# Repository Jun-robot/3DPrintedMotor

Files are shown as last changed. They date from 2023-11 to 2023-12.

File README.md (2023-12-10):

# 3DPrintedMotor

## Overview
3Dプリンタで作る自作モーターのリポジトリです。

アイデアがより的確に実現できるようになるといいなと思って開発中です。

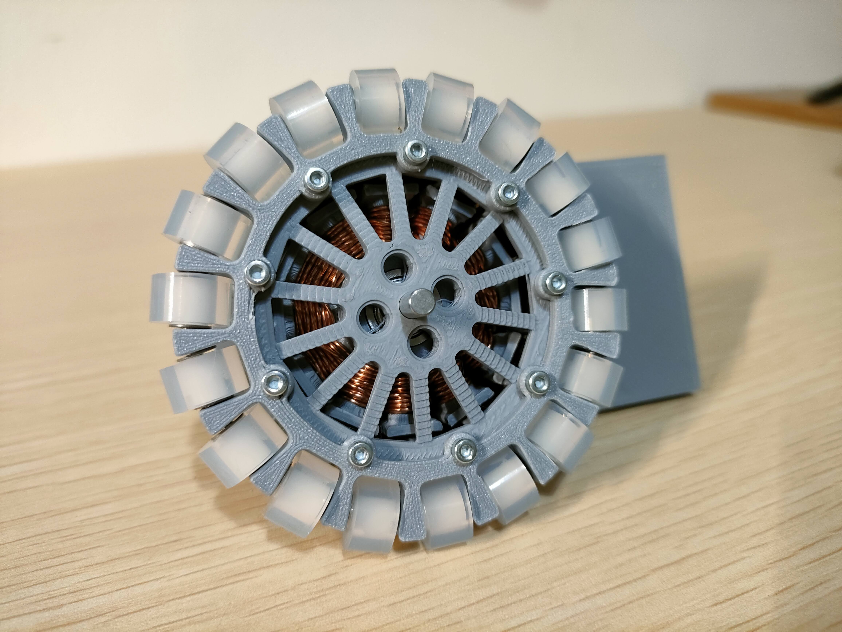
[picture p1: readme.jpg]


## How to make
#### 必要なもの
- 3Dプリンタ
- ネジとかコイルとかベアリングとか

#### 作り方
1. "3Dmodels"の中にある5つのSTLファイルをダウンロード！！
1. 3Dプリンタで印刷！！
1. コイル巻いたり、組み立てたり
   - 必要な部品の型番は今後、追記していきます。
	 - 今のところ、設計データから推定できます。

## Concept
- 3Dプリンタさえあれば手に入る
  - あとは、ネジやコイルの規格品のみで作成可能！
- 開発物に適した形状、性能に。
  - アイデアの妥協をなくし、作りたいモノに最適化

## Mechanism
Fusion360で作成

https://a360.co/3StNydJ

## Circuit
KiCADで設計

DRV8332とSTM32F446を使用した自作基板

磁気エンコーダーはAS5601を使用

## Software
VScode + PlatformIOでArduinoで開発

現在は、強制転流。
今後フィードバック制御をかけていく予定

## Achievement
- サイエンスキャッスル2022関東大会 口頭発表
- [未踏ジュニア2023採択](https://jr.mitou.org/projects/2023/3d_printed_brushless_motor)
- MakerFaireTokyo2023 未踏ジュニアブースにて展示
- 未踏ジュニア成果報告会2023 発表

## Licence
MIT

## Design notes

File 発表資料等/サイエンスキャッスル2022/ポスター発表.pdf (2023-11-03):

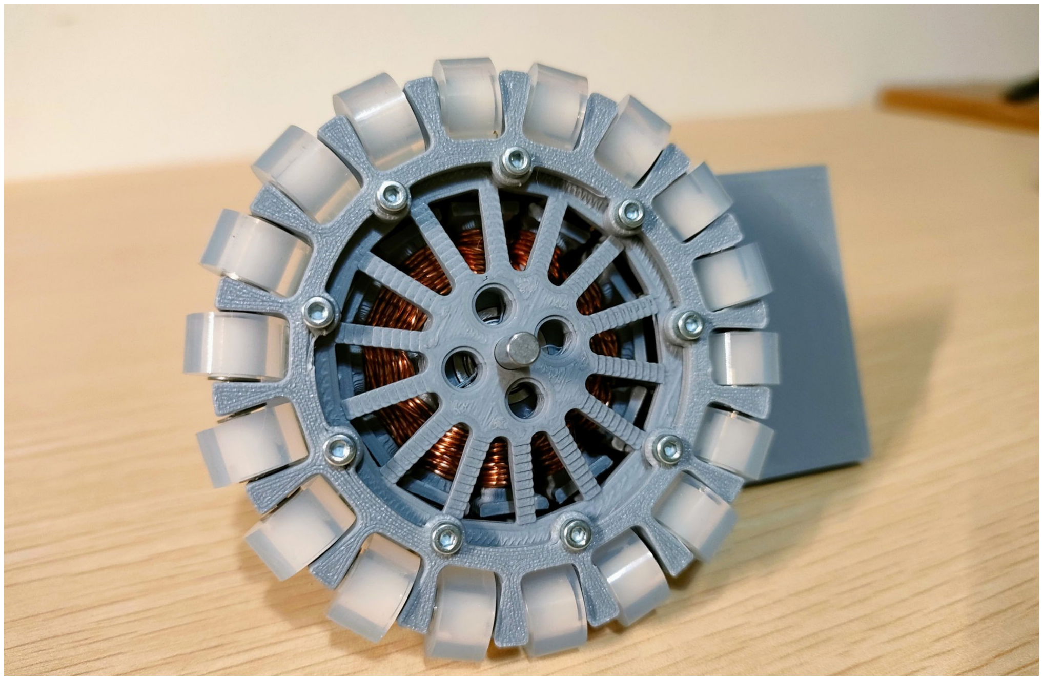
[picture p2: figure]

使用部品
プリンタで構造部品を製作 D3
磁、ベアリング、ボルト、銅線
石は市販品を使用
現機体のモーターとの比較
ら か g126、が た っ な に 径 大
へ軽量化 g123
マシン内、薄く小型化したため
の部品配置の自由度の向上

目標

# 。誰もが思い描いたものを自由に形にできる世界を作る

## !今回は僕の考えた最強のロボットに必要なモーターを開発 →

# に最適化した RoboCupJunior 軽量低コスト駆動用アクチュエーターの開発

## ( 年 2 慶應義塾志木高等学校 ( 齋藤淳平

# とは RoboCupJunior

概要
国内では毎年数千人が、世界数十カ国で開催されていて
歳までの学生を対象にした世界的なロボコン 19、参加する 主なルール
台の自律型ロボット 2 各チーム・
専用フィールドで試合・
ゴールに入れたら得点・
まで g1100 重量は・
以内 cm22 高さ、cm22 直径・

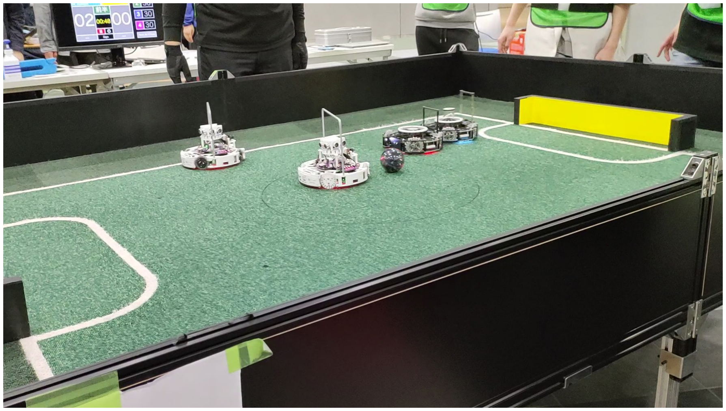
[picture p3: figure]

で優勝できるロボット RoboCup、最強のロボットとは

# ?強くなるにはお金が必要

に参加し続けてきたこと RoboCupJunior 中学生の頃から 。以下の負のループが生まれていることに気づいた、で
高性能なモーターを持っている機体には勝ちにくい
↓
( 分解して性能上げたりできない ( モーターは改良がむずかしい
↓
高性能なモーターを買う、上位を目指すにつれ
モーターを自由に誰でも自作できる : 仮説
ようになれば平等に戦えるのでは

# 開発のコンセプト

つの 3 高性能なモーターを超すために、自作モーターで 。コンセプトを定めた
最低限の強度
何年も使い続けるわけではない
プリンタ部品を活用し軽量低コスト化を実現 D3
完全オーダメイド
他のユニットを考慮した部品配置
ブラシレス方式を採用
ブラシによる損失をなくし効率化

# 今回のプロトタイプ

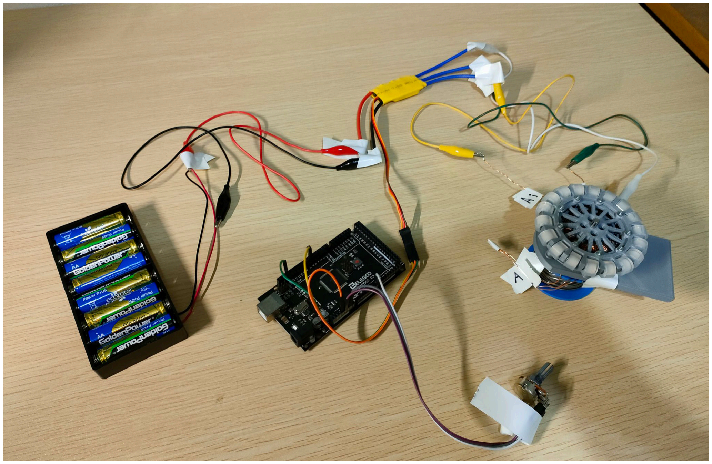
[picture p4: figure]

回り始めにくい
脱調しやすい
低速回転ができない
↓
を開発しフィー MD ブラシレス
。ドバック制御をかける
回転、の開発が完了したら MD
消費電力などのデー、トルク、数
。タもとる

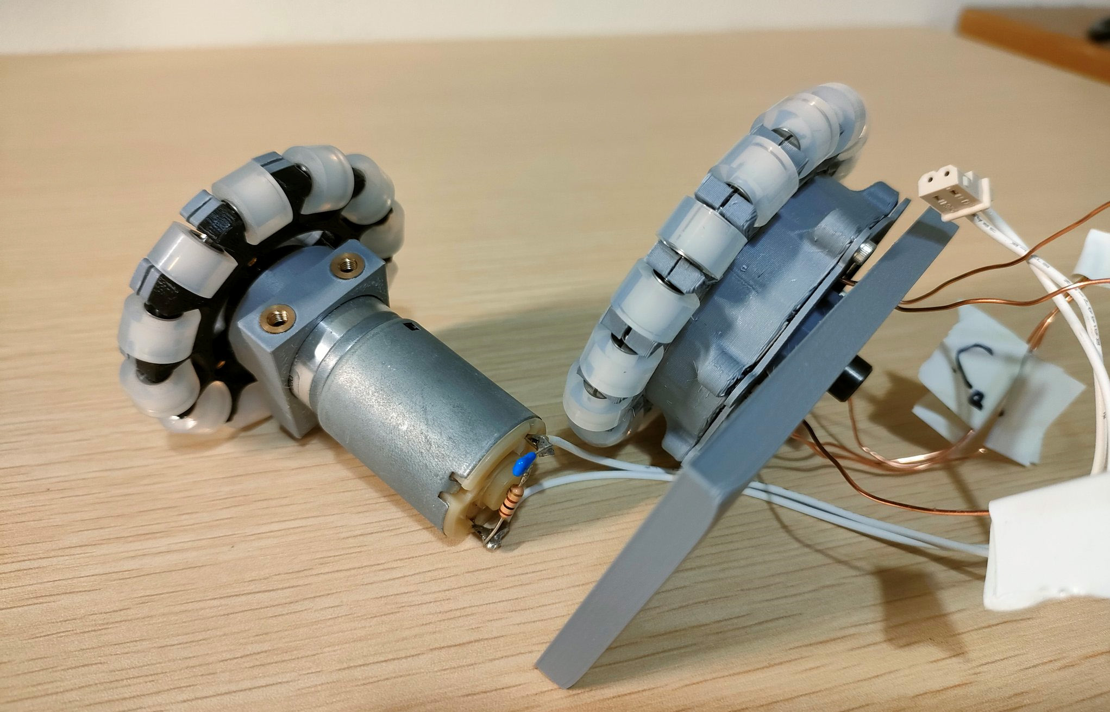
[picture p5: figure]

# 今回の課題

開発の経過から公開

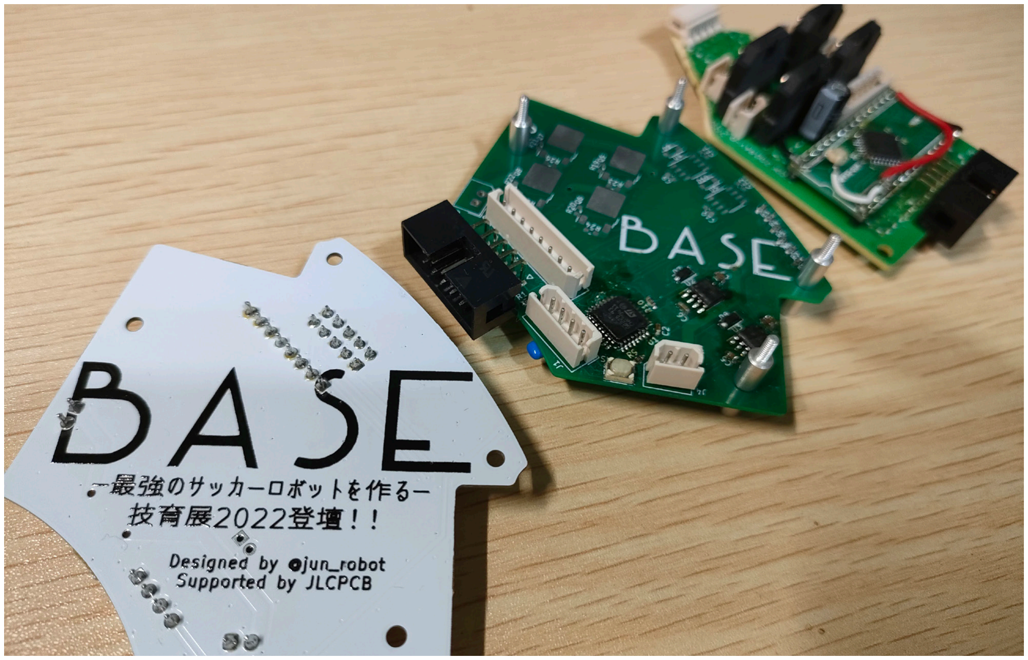
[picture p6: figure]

やブログへ定期的に投稿しフィードバックをもら Twitter ネットの情報に助けれてきた、私自身ずっと独学で。う
。誰かの助けになれるように、ので
部品性能からスキル対決に
性能の高い既製品を使えば勝てるという今の競技会の定
真のエンジニアリング能力が評価さ、そして。石を覆す
。れる競技会へ

# オープンソース化

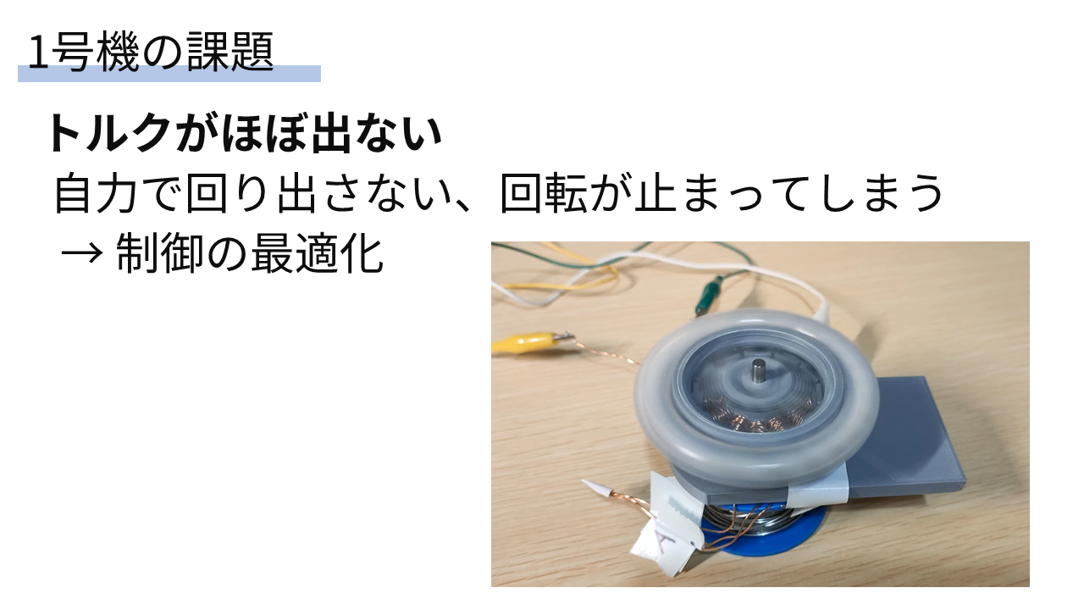
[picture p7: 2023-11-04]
発表資料等/未踏ジュニア/成果報告会/スライド12.PNG

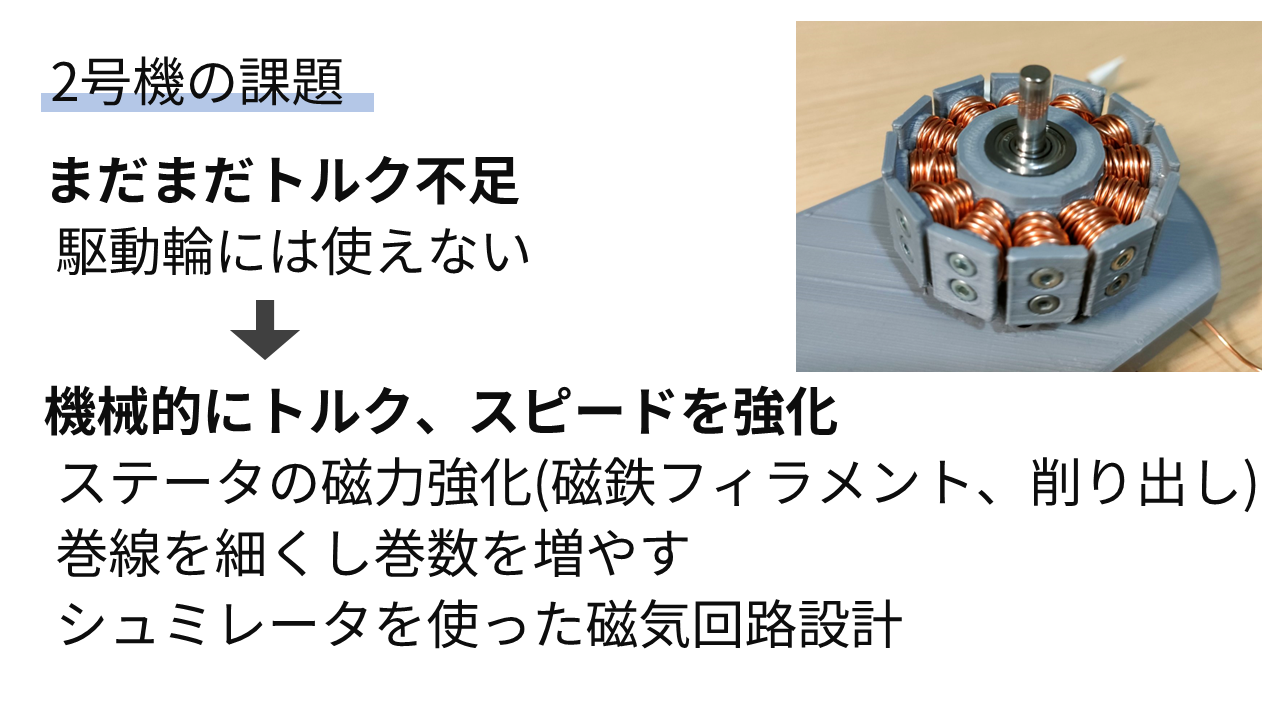
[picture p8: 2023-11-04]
発表資料等/未踏ジュニア/成果報告会/スライド16.PNG

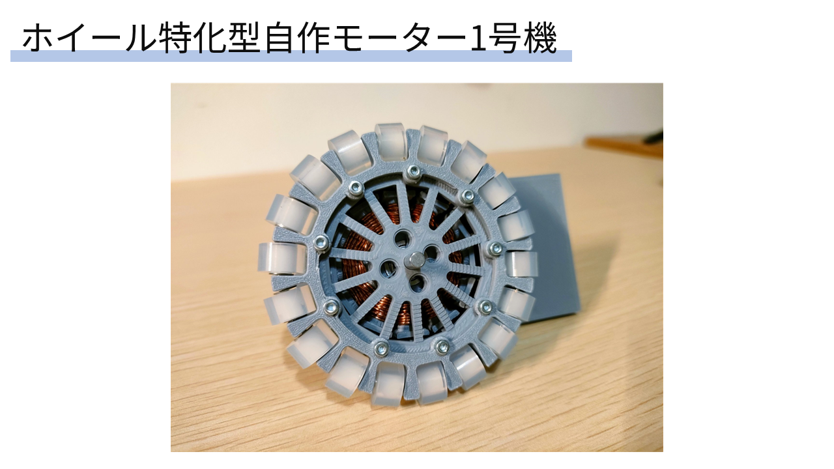
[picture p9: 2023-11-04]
発表資料等/未踏ジュニア/成果報告会/スライド11.PNG

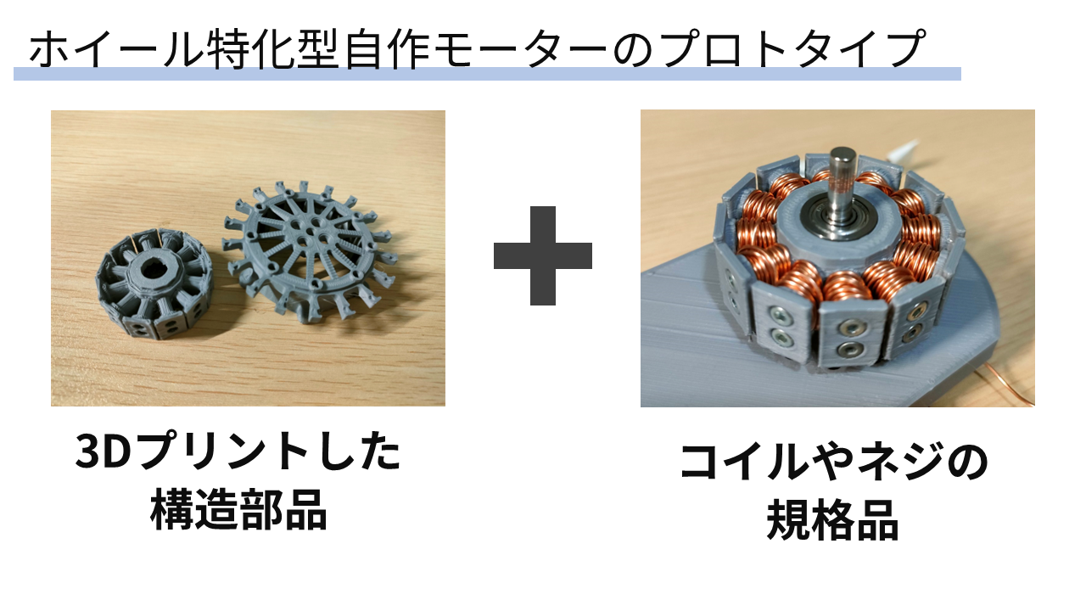
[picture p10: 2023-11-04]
発表資料等/未踏ジュニア/成果報告会/スライド10.PNG

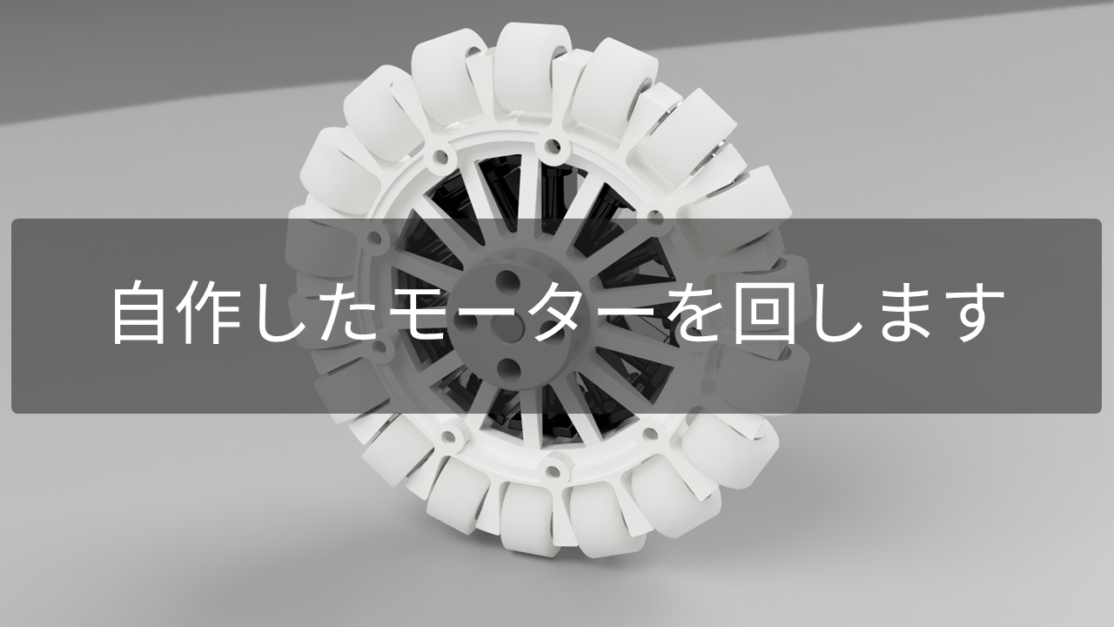
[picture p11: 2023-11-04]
発表資料等/未踏ジュニア/成果報告会/スライド2.PNG

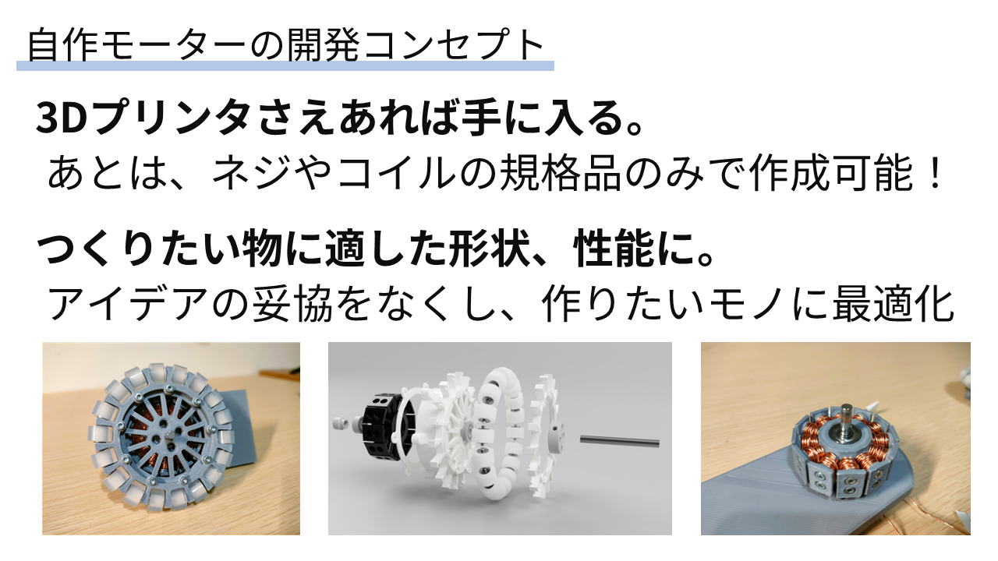
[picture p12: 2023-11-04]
発表資料等/未踏ジュニア/成果報告会/スライド8.PNG

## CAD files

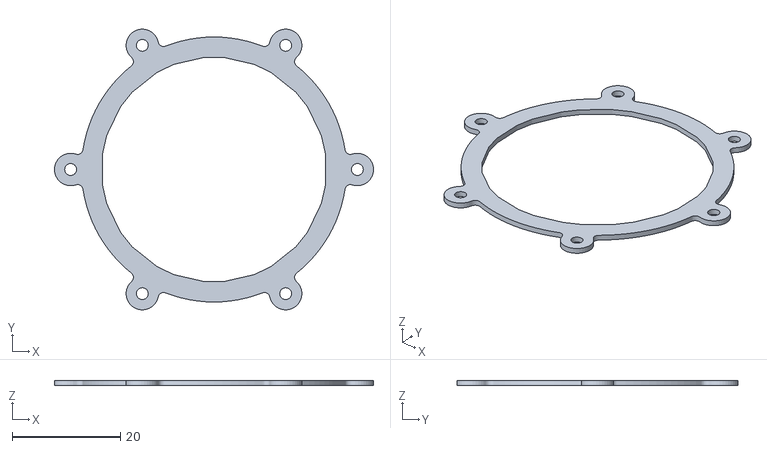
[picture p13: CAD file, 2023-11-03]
3Dmodels/fastener.stl
59.0 x 51.9 x 1.00

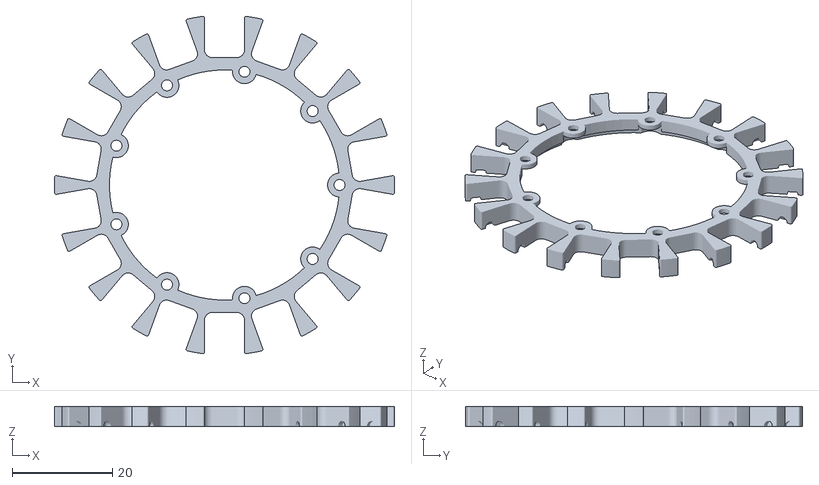
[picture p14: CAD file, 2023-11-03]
3Dmodels/omni.stl
68.0 x 67.4 x 4.00

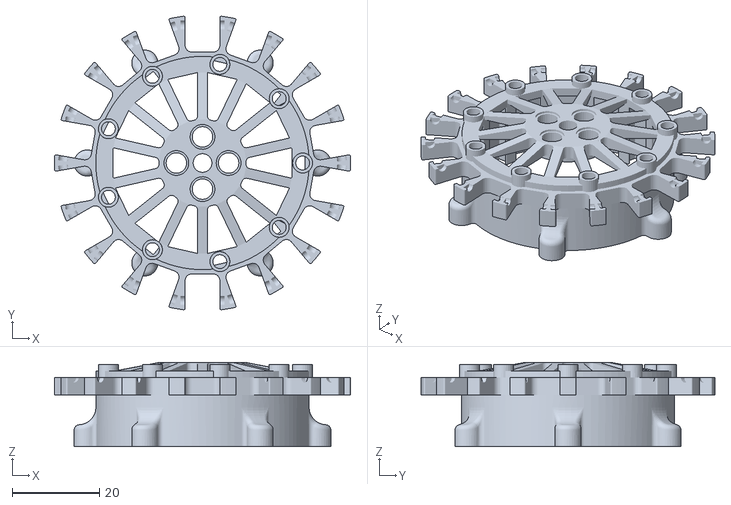
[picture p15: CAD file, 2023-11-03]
3Dmodels/rotor.stl
68.0 x 67.4 x 19.3

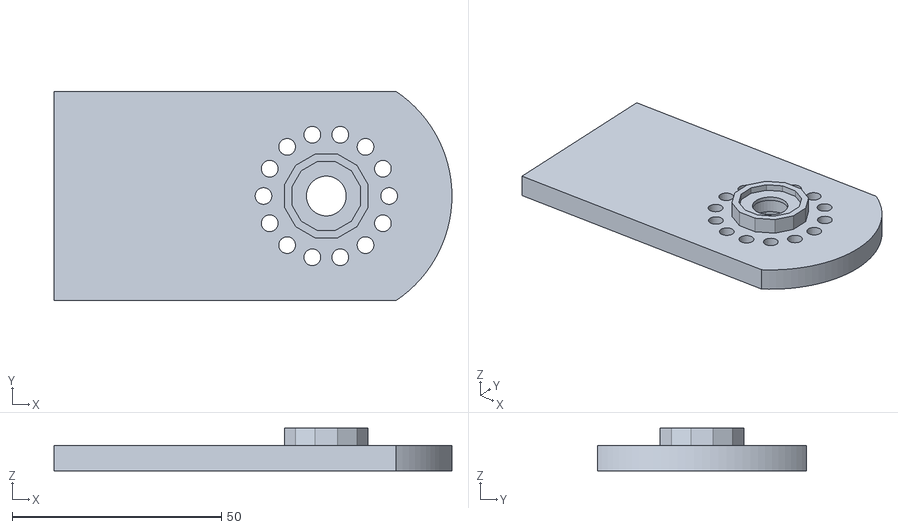
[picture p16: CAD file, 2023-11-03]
3Dmodels/mount.stl
95.0 x 50.0 x 10.2

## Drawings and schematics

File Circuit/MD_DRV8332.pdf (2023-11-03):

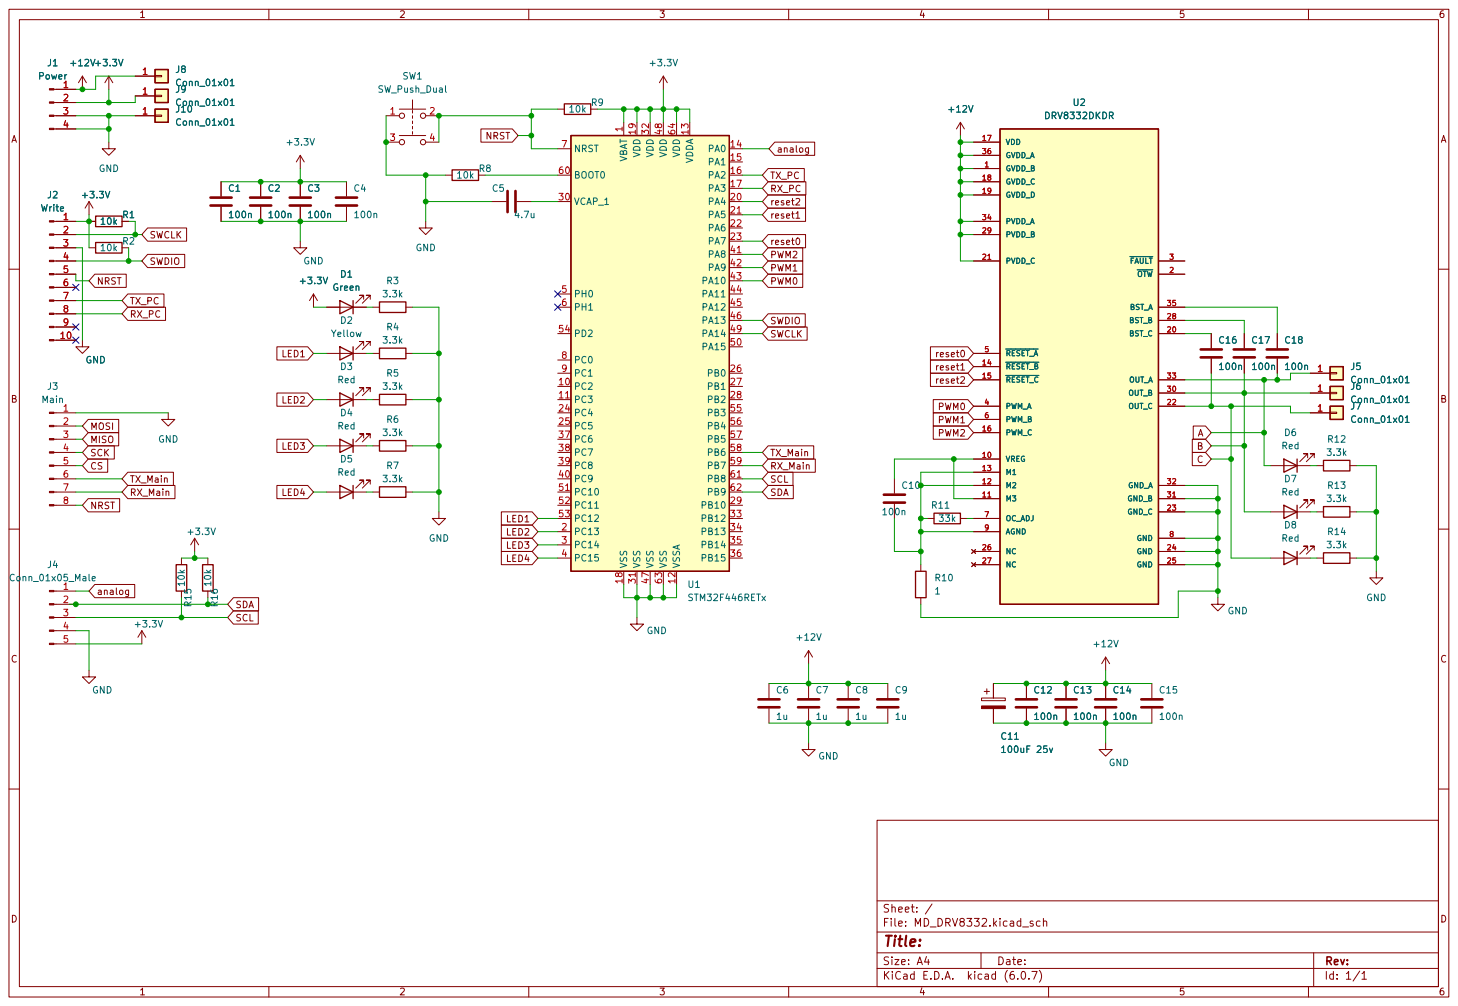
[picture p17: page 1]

1 PC2 10 PC3 11 VSSA 12 VDDA 13 PA0 14 PA1 15 PA2 16 PA3 17 VSS 18 VDD 19 PC13 2 PA4 20 PA5 21 PA6 22 PA7 23 PC4 24 PC5 25 PB0 26 PB1 27 PB2 28 PB10 29 PC14 3 VCAP_1 30 VSS 31 VDD 32 PB12 33 PB13 34 PB14 35 PB15 36 PC6 37 PC7 38 PC8 39 PC15 4 PC9 40 PA8 41 PA9 42 PA10 43 PA11 44 PA12 45 PA13 46 VSS 47 VDD 48 PA14 49 PH0 5 PA15 50 PC10 51 PC11 52 PC12 53 PD2 54 PB3 55 PB4 56 PB5 57 PB6 58 PB7 59 PH1 6 BOOT0 60 PB8 61 PB9 62 VSS 63 VDD 64 NRST 7 PC0 8 PC1 9 U1STM32F446RETx D6 Red GND

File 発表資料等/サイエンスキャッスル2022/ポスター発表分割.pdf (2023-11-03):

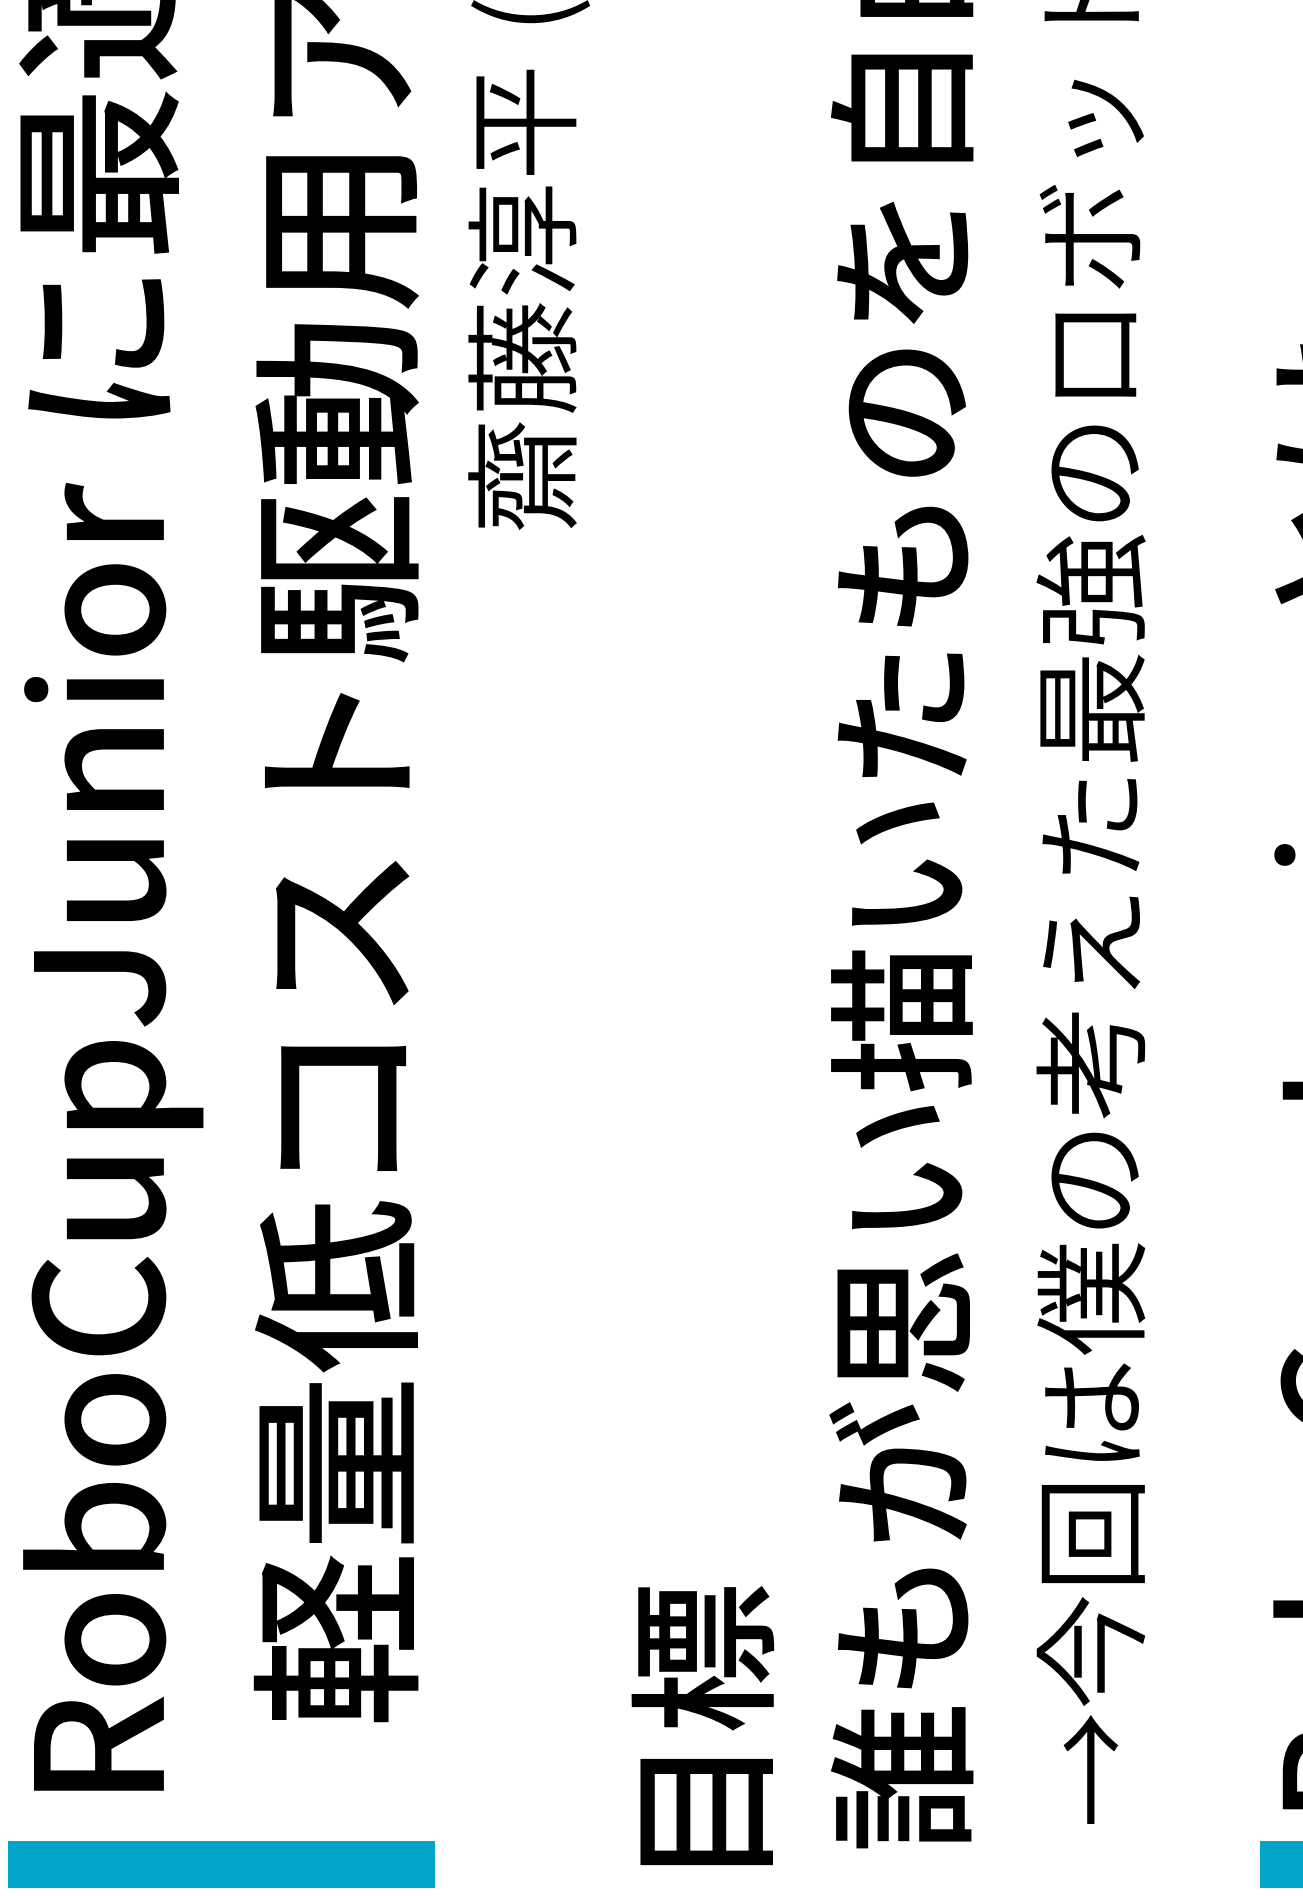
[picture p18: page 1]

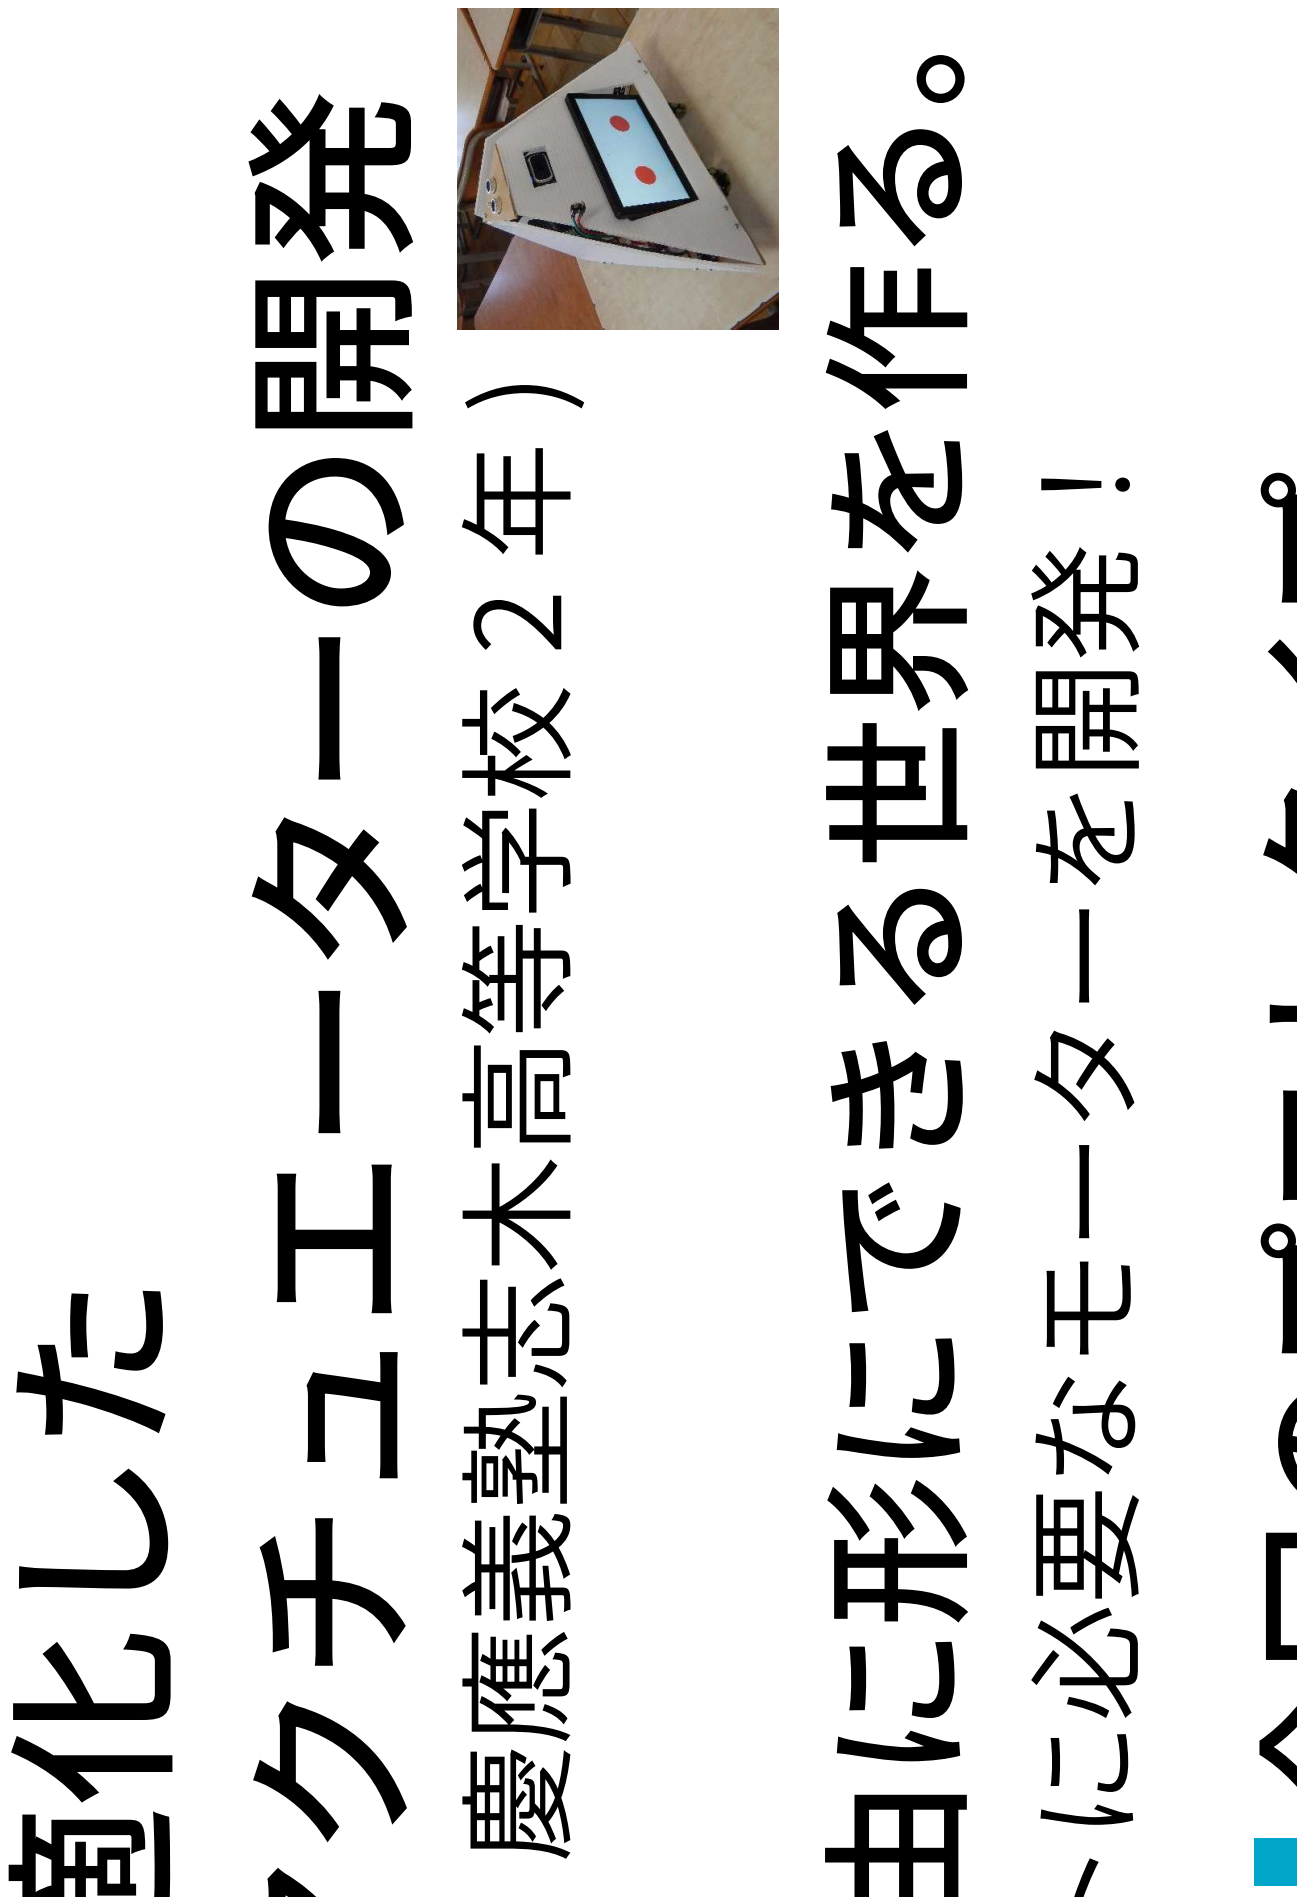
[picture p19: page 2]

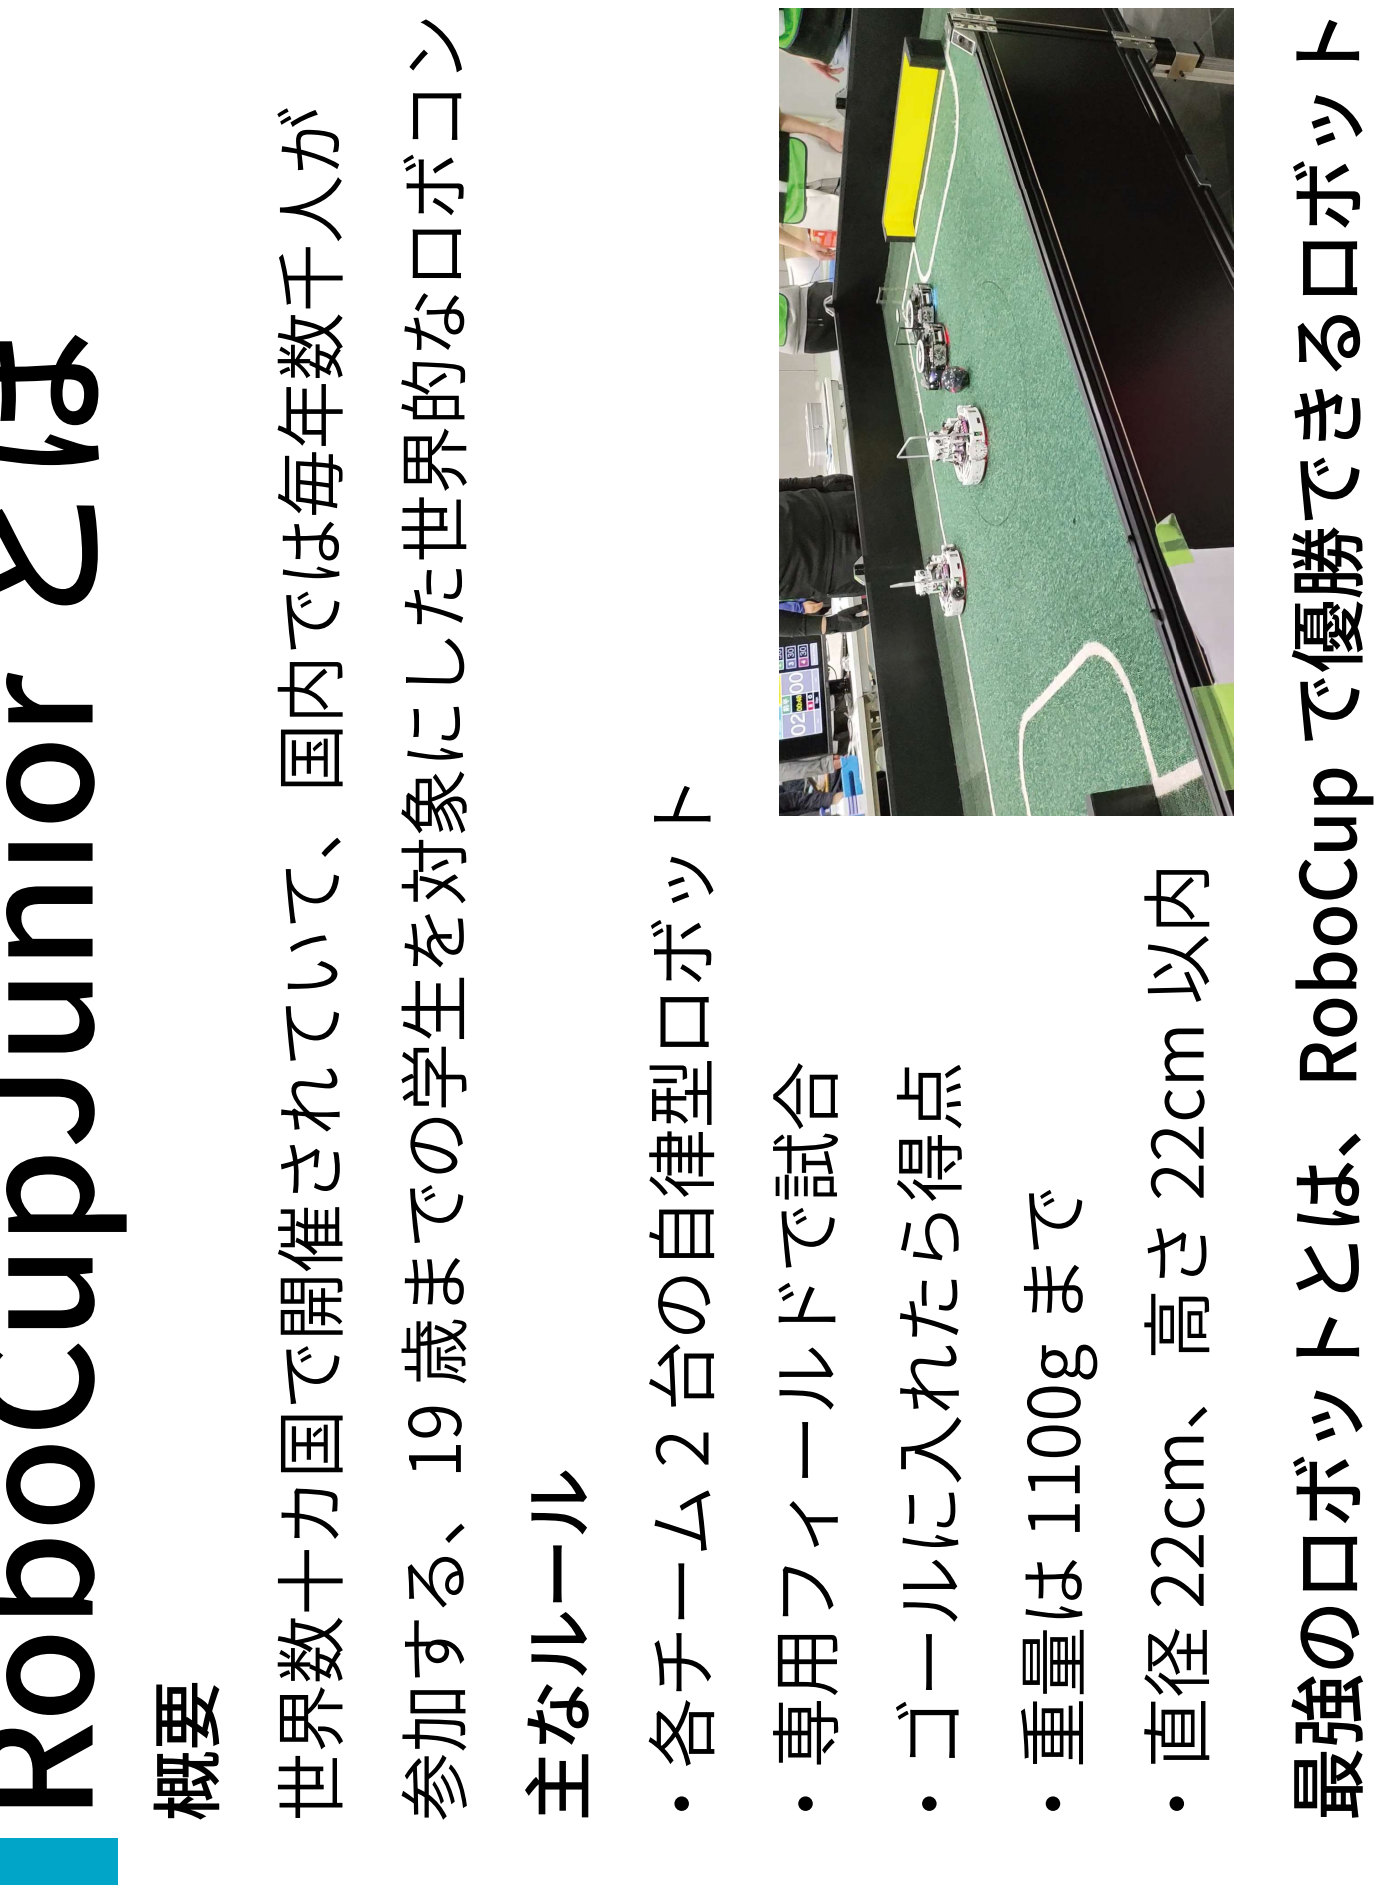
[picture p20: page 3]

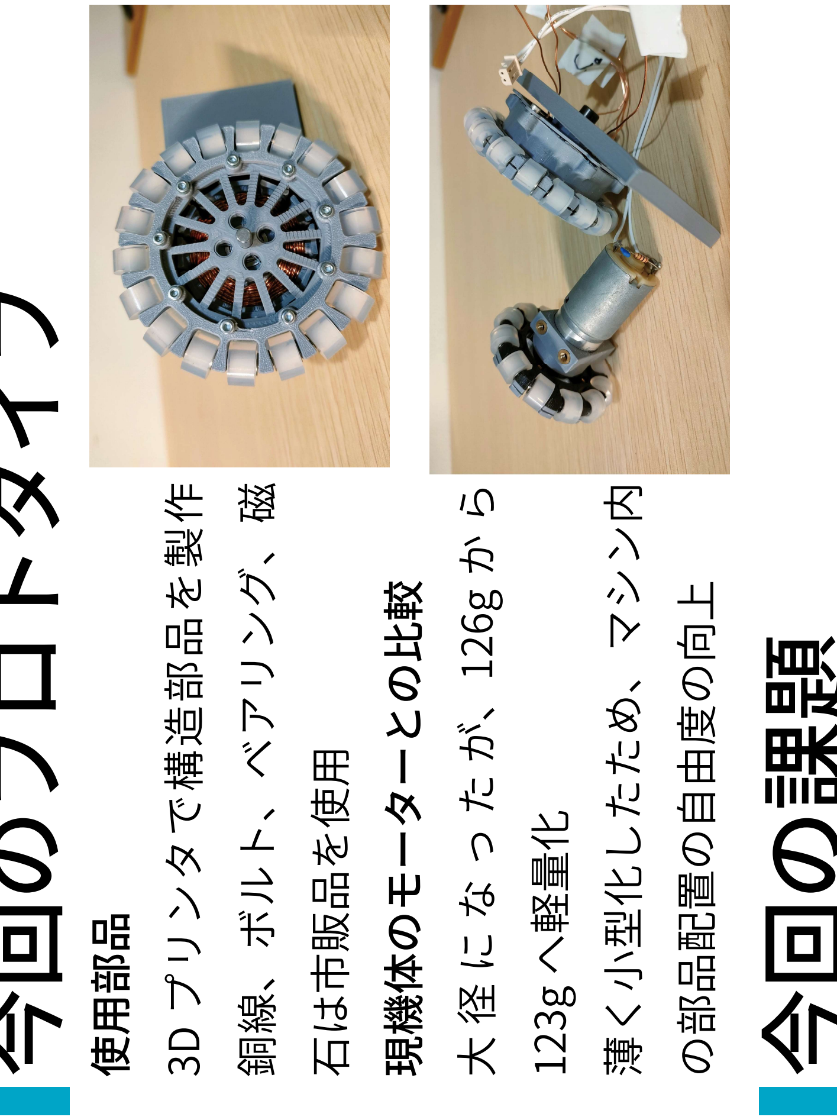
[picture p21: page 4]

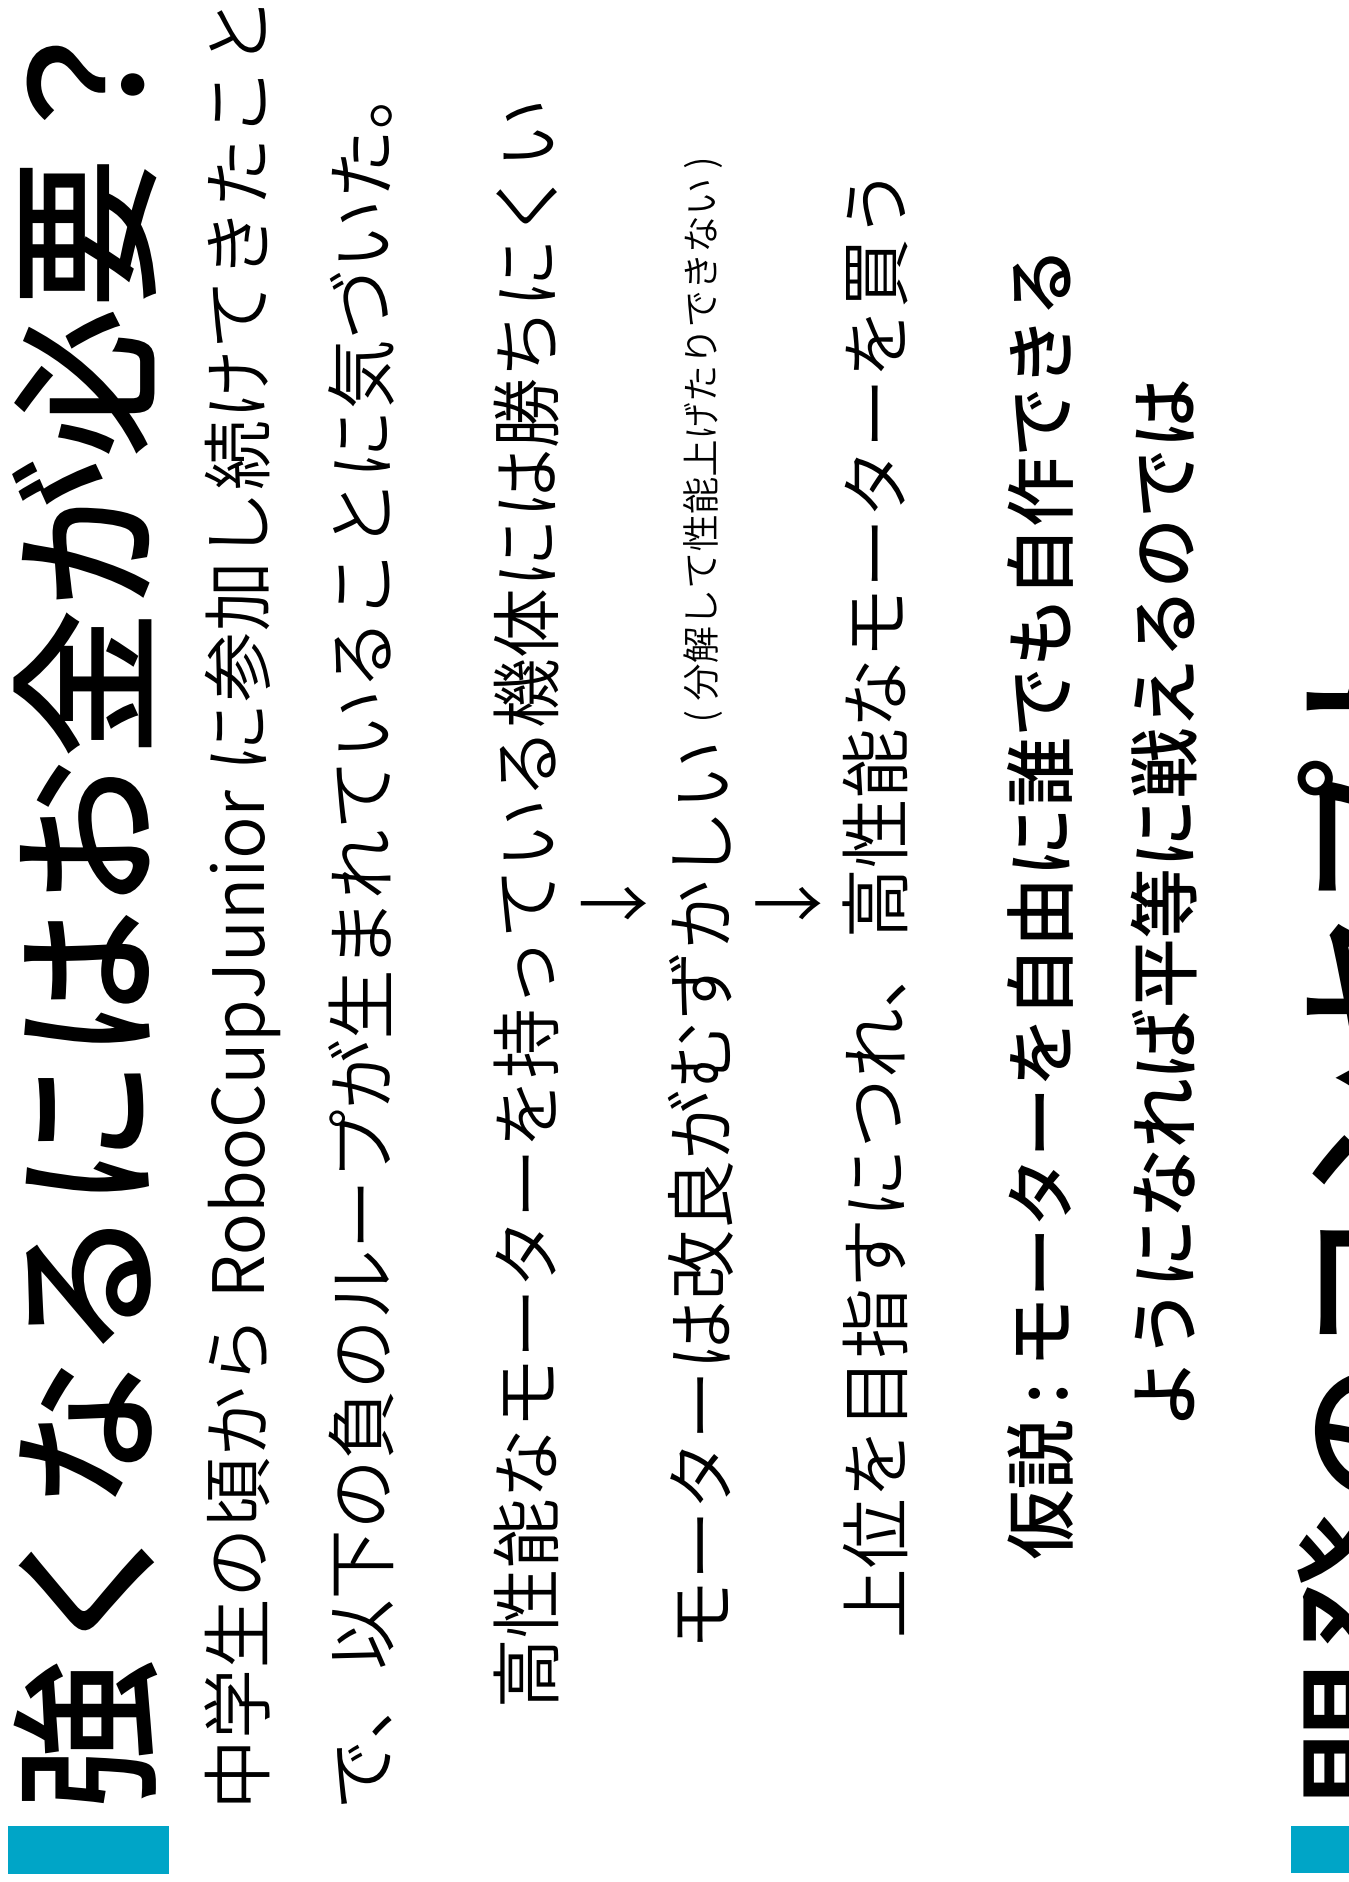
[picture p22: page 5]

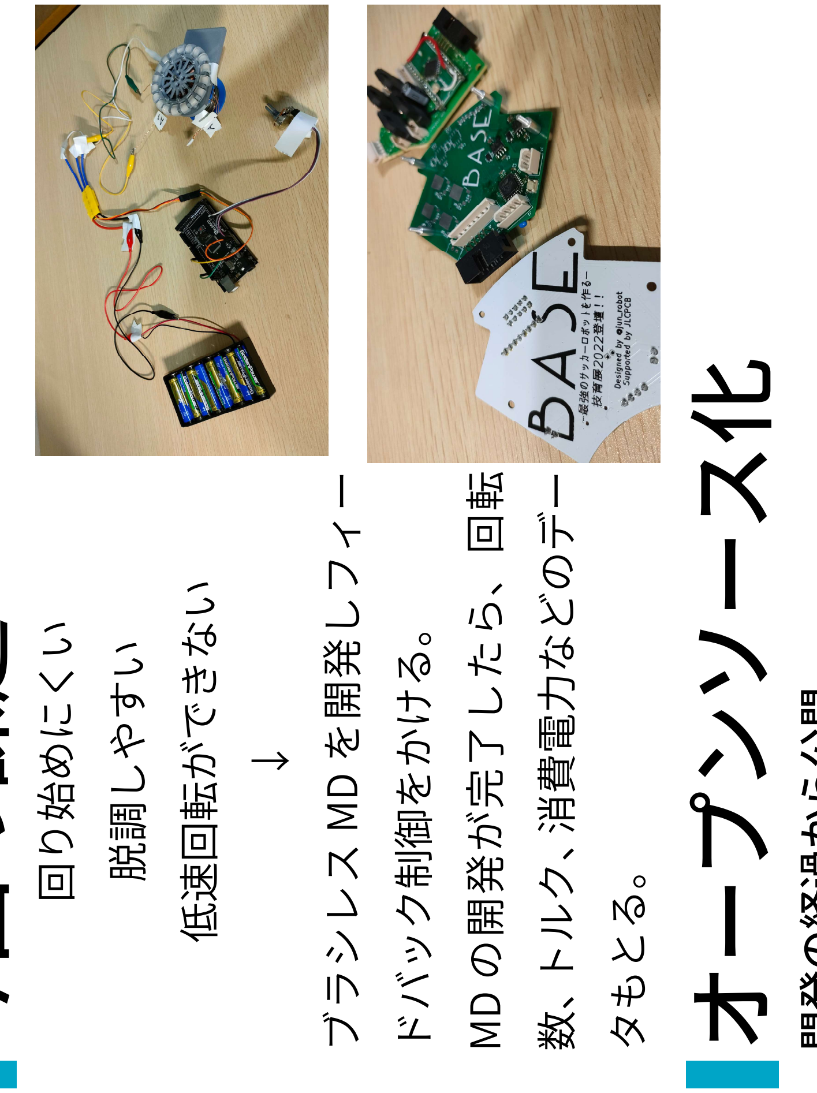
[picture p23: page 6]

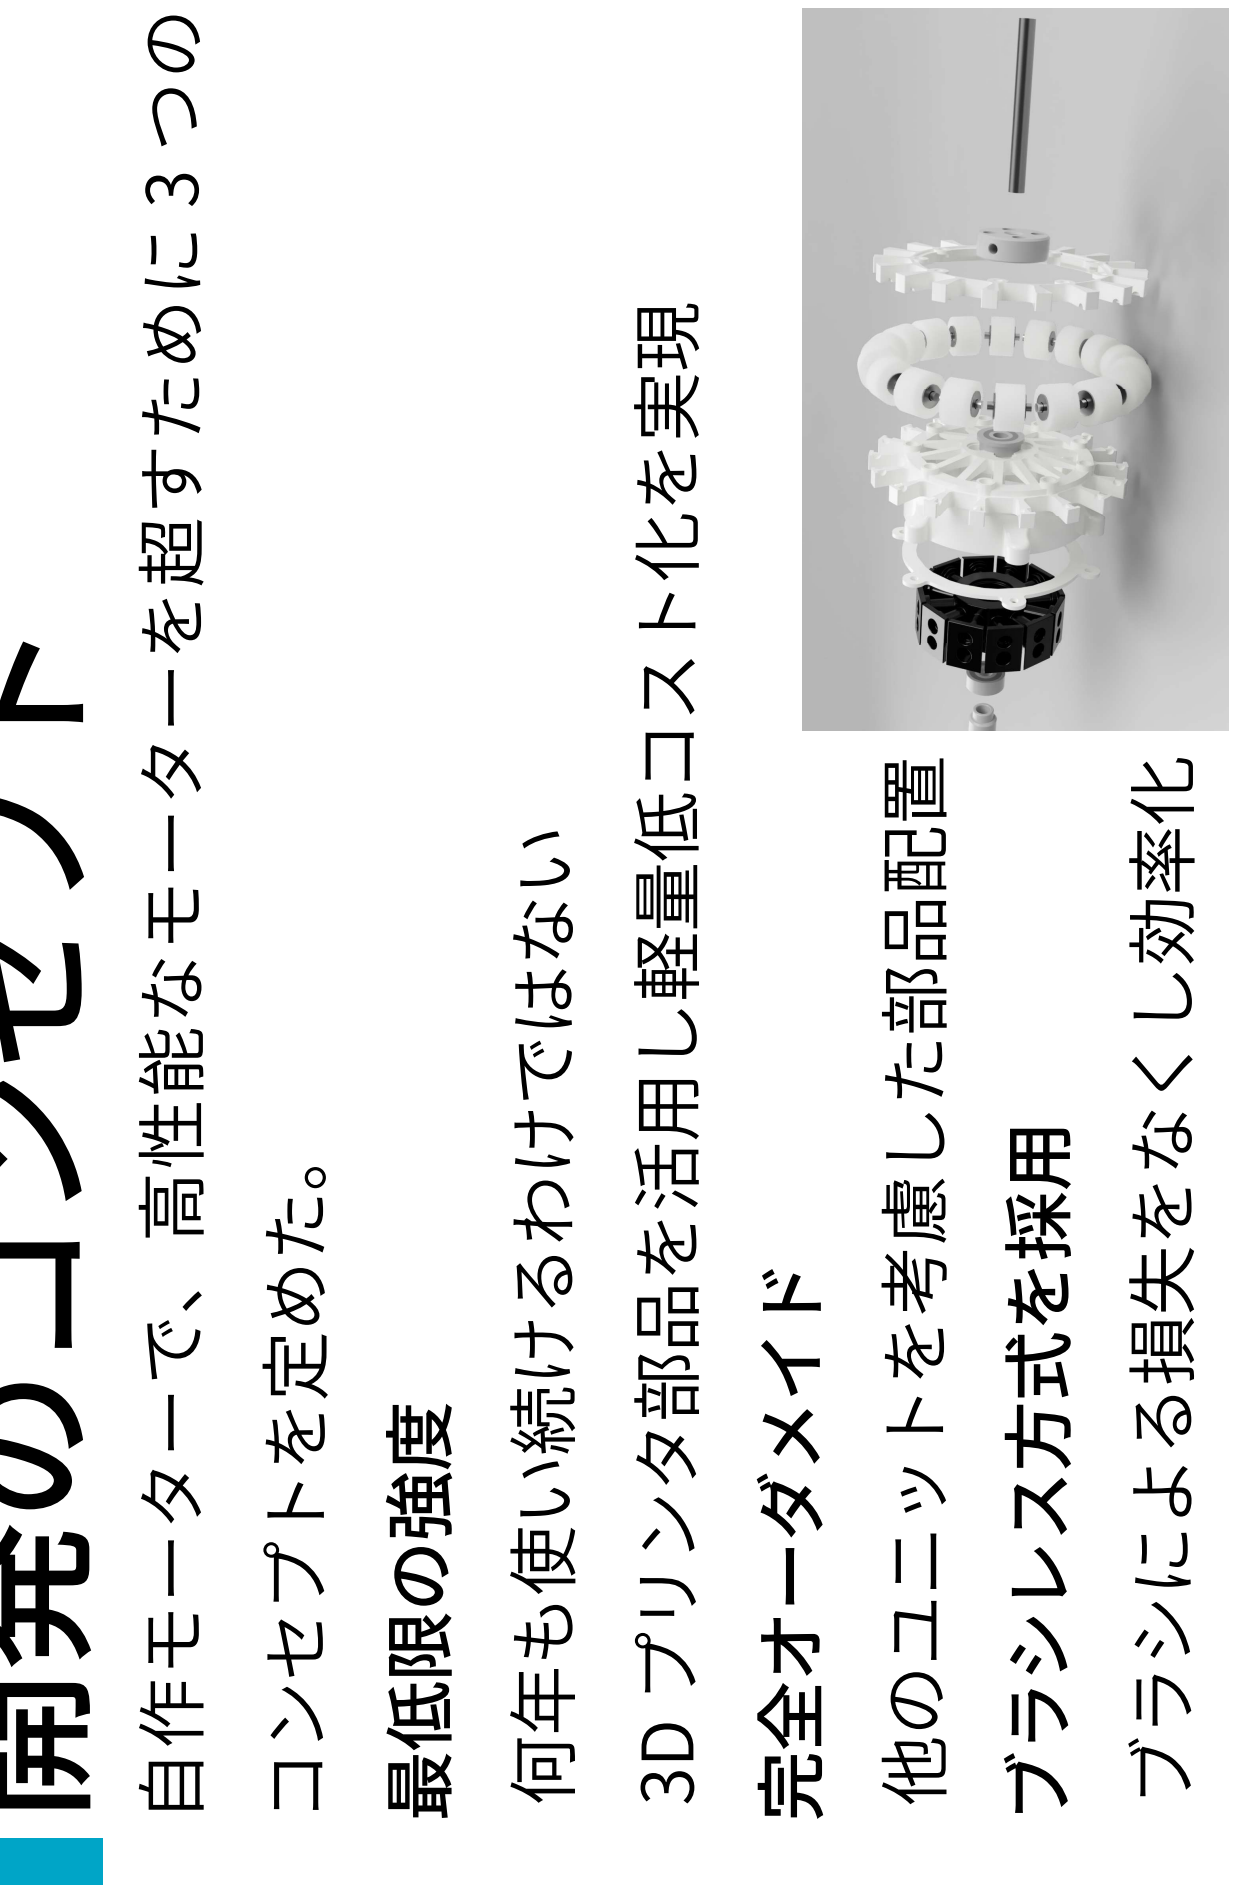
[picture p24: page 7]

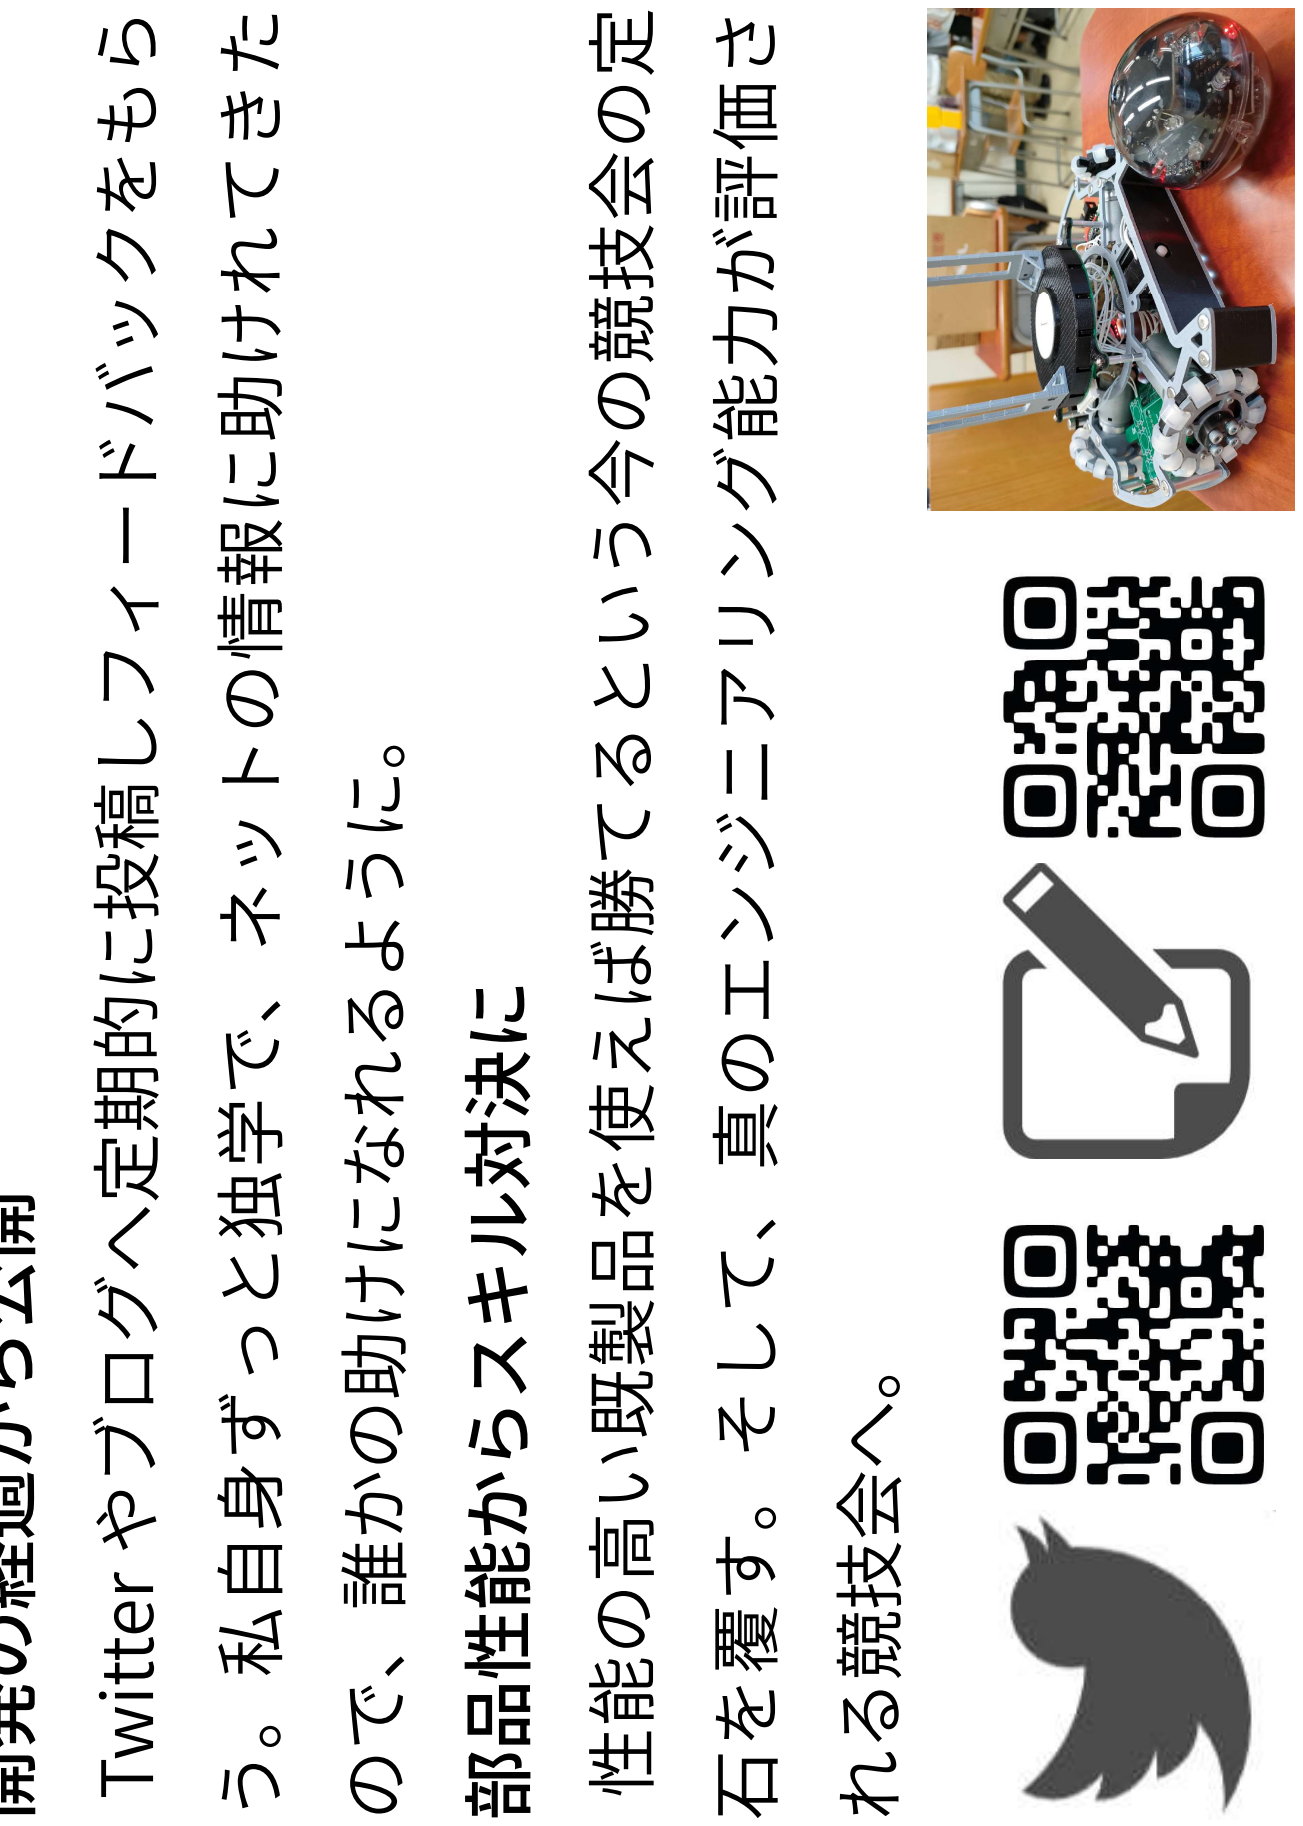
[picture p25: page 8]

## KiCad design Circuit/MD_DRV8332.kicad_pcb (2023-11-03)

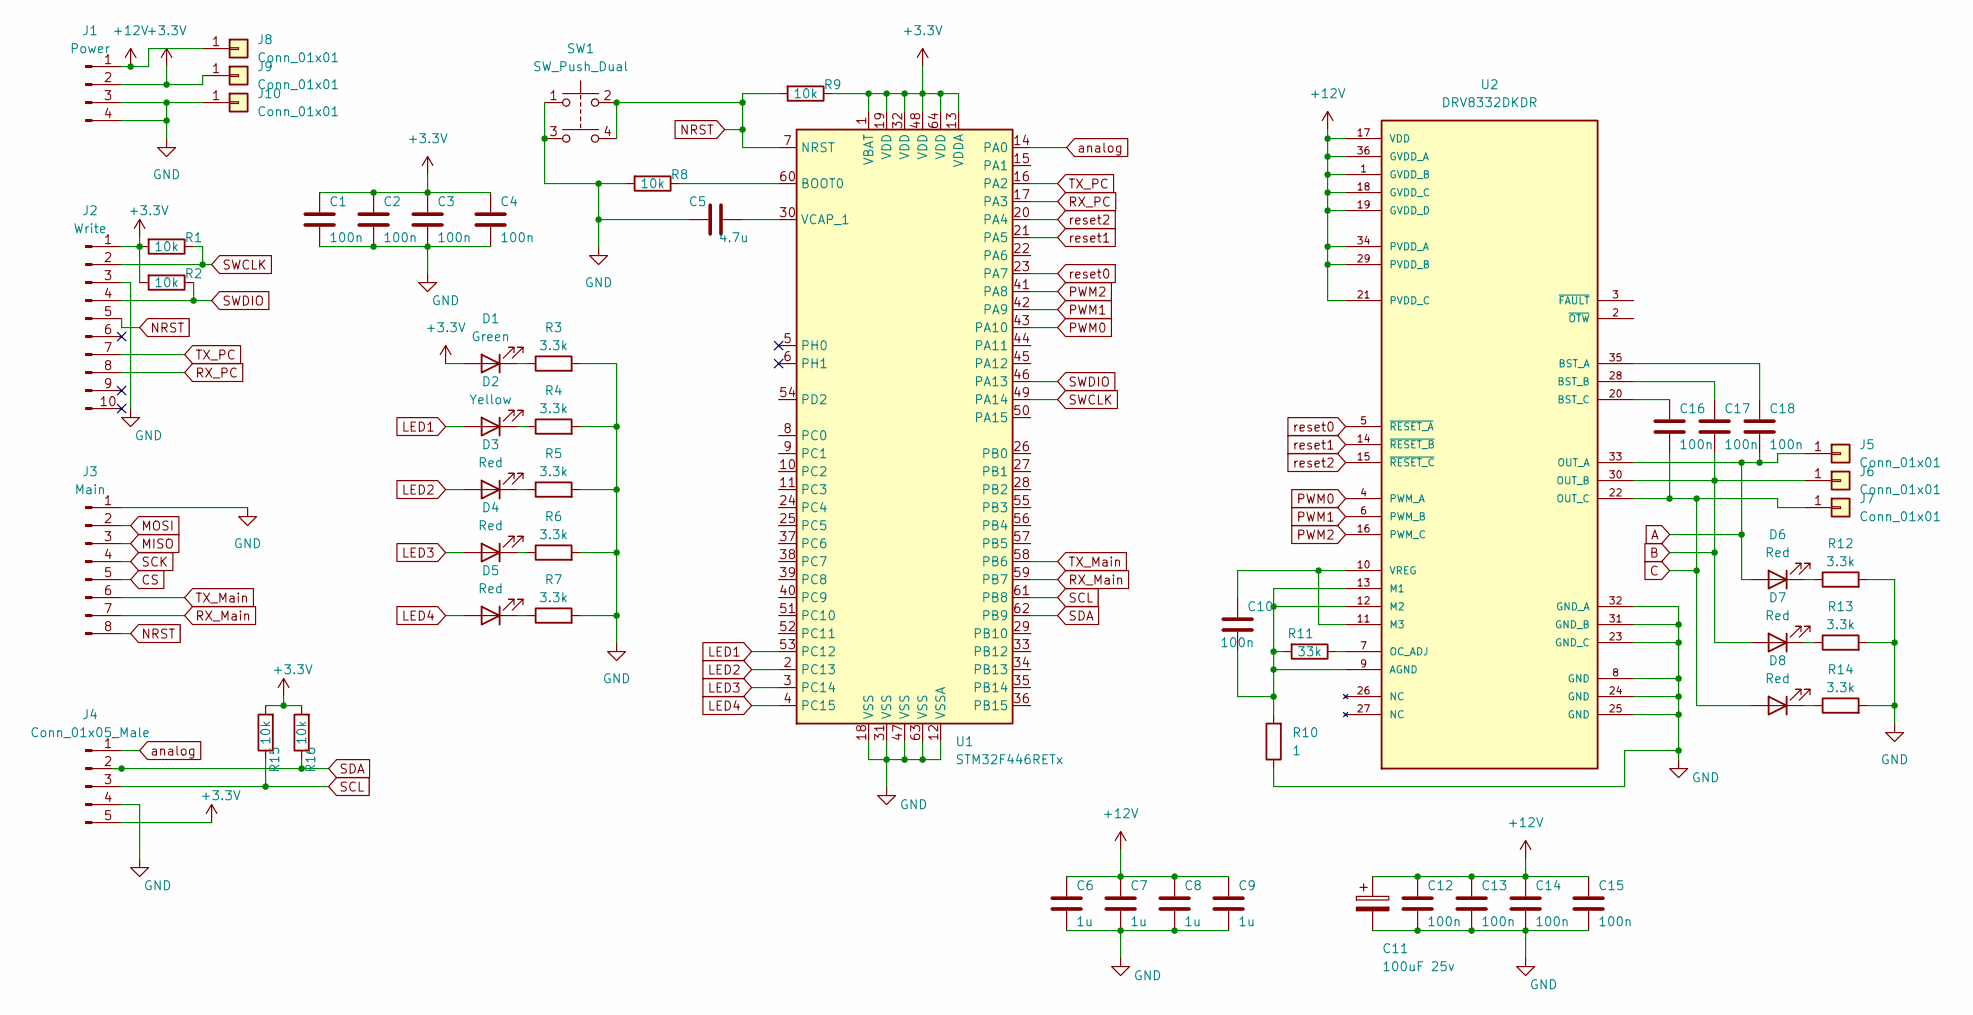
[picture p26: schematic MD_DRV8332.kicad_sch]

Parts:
C1, C2, C3, C4, C10, C12, C13, C14, C15, C16, C17, C18: 100n; C_0603_1608Metric_Pad1.08x0.95mm_HandSolder; LCSC C307331
C5: 4.7u; C_0603_1608Metric_Pad1.08x0.95mm_HandSolder; LCSC C23733
C6, C7, C8, C9: 1u; C_0603_1608Metric_Pad1.08x0.95mm_HandSolder; LCSC C52923
C11: 100uF 25v; CP_Radial_D5.0mm_P2.00mm
D1: Green; D_0603_1608Metric_Pad1.05x0.95mm_HandSolder; LCSC C72043
D2: Yellow; D_0603_1608Metric_Pad1.05x0.95mm_HandSolder; LCSC C72038
D3, D4, D5, D6, D7, D8: Red; D_0603_1608Metric_Pad1.05x0.95mm_HandSolder; LCSC C2286
J1: Power; Molex_SPOX_5267-04A_1x04_P2.50mm_Vertical
J2: Write; IDC-Header_2x05_P2.54mm_Horizontal
J3: Main; Molex_SPOX_5267-08A_1x08_P2.50mm_Vertical
J4: Conn_01x05_Male; Molex_SPOX_5267-05A_1x05_P2.50mm_Vertical
J5, J6, J7, J8, J9: Conn_01x01; TestPoint_THTPad_D4.0mm_Drill2.0mm
J10: Conn_01x01; TestPoint_THTPad_4.0x4.0mm_Drill2.0mm
R1, R2, R8, R9, R15, R16: 10k; R_0603_1608Metric_Pad0.98x0.95mm_HandSolder; LCSC C25744
R3, R4, R5, R6, R7, R12, R13, R14: 3.3k; R_0603_1608Metric_Pad0.98x0.95mm_HandSolder; LCSC C25890
R10: 1; R_0603_1608Metric_Pad0.98x0.95mm_HandSolder; LCSC C25086
R11: 33k; R_0603_1608Metric_Pad0.98x0.95mm_HandSolder; LCSC C25792
SW1: SW_Push_Dual; TACT2; LCSC C318884
U1: STM32F446RETx; LQFP-64_10x10mm_P0.5mm; LCSC C69336
U2: DRV8332DKDR; HTSSOP36; PARTREV G

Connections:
+3.3V: C1.1, C2.1, C3.1, C4.1, D1.2 (A), J1.2, J2.1, J4.5, J9.1, R1.2, R2.2, R9.1, R15.2, R16.2, U1.1 (VBAT), U1.13 (VDDA), U1.19 (VDD), U1.32 (VDD), U1.48 (VDD), U1.64 (VDD)
+12V: C6.1, C7.1, C8.1, C9.1, C11.1, C12.1, C13.1, C14.1, C15.1, J1.1, J8.1, U2.1 (GVDD_B), U2.17 (VDD), U2.18 (GVDD_C), U2.19 (GVDD_D), U2.21 (PVDD_C), U2.29 (PVDD_B), U2.34 (PVDD_A), U2.36 (GVDD_A)
A: C18.2, D6.2 (A), J5.1, U2.33 (OUT_A)
B: C17.2, D7.2 (A), J6.1, U2.30 (OUT_B)
C: C16.2, D8.2 (A), J7.1, U2.22 (OUT_C)
CS: J3.5
GND: C1.2, C2.2, C3.2, C4.2, C5.1, C6.2, C7.2, C8.2, C9.2, C11.2, C12.2, C13.2, C14.2, C15.2, J1.3, J1.4, J2.3, J3.1, J4.4, J10.1, R3.2, R4.2, R5.2, R6.2, R7.2, R8.2, R10.1, R12.2, R13.2, R14.2, SW1.1, SW1.3, U1.12 (VSSA), U1.18 (VSS), U1.31 (VSS), U1.47 (VSS), U1.63 (VSS), U2.8 (GND), U2.23 (GND_C), U2.24 (GND), U2.25 (GND), U2.31 (GND_B), U2.32 (GND_A)
LED1: D2.2 (A), U1.53 (PC12)
LED2: D3.2 (A), U1.2 (PC13)
LED3: D4.2 (A), U1.3 (PC14)
LED4: D5.2 (A), U1.4 (PC15)
MISO: J3.3
MOSI: J3.2
NRST: J2.5, J3.8, R9.2, SW1.2, SW1.4, U1.7 (NRST)
unnamed: C5.2, U1.30 (VCAP_1)
unnamed: C10.1, U2.10 (VREG), U2.11 (M3)
unnamed: C10.2, R10.2, R11.2, U2.9 (AGND), U2.12 (M2), U2.13 (M1)
unnamed: C16.1, U2.20 (BST_C)
unnamed: C17.1, U2.28 (BST_B)
unnamed: C18.1, U2.35 (BST_A)
unnamed: D1.1 (K), R3.1
unnamed: D2.1 (K), R4.1
unnamed: D3.1 (K), R5.1
unnamed: D4.1 (K), R6.1
unnamed: D5.1 (K), R7.1
unnamed: D6.1 (K), R12.1
unnamed: D7.1 (K), R13.1
unnamed: D8.1 (K), R14.1
unnamed: R8.1, U1.60 (BOOT0)
unnamed: R11.1, U2.7 (OC_ADJ)
PWM0: U1.43 (PA10), U2.4 (PWM_A)
PWM1: U1.42 (PA9), U2.6 (PWM_B)
PWM2: U1.41 (PA8), U2.16 (PWM_C)
RX_Main: J3.7, U1.59 (PB7)
RX_PC: J2.8, U1.17 (PA3)
SCK: J3.4
SCL: J4.3, R15.1, U1.61 (PB8)
SDA: J4.2, R16.1, U1.62 (PB9)
SWCLK: J2.2, R1.1, U1.49 (PA14)
SWDIO: J2.4, R2.1, U1.46 (PA13)
TX_Main: J3.6, U1.58 (PB6)
TX_PC: J2.7, U1.16 (PA2)
analog: J4.1, U1.14 (PA0)
reset0: U1.23 (PA7), U2.5 (~RESET_A)
reset1: U1.21 (PA5), U2.14 (~RESET_B)
reset2: U1.20 (PA4), U2.15 (~RESET_C)

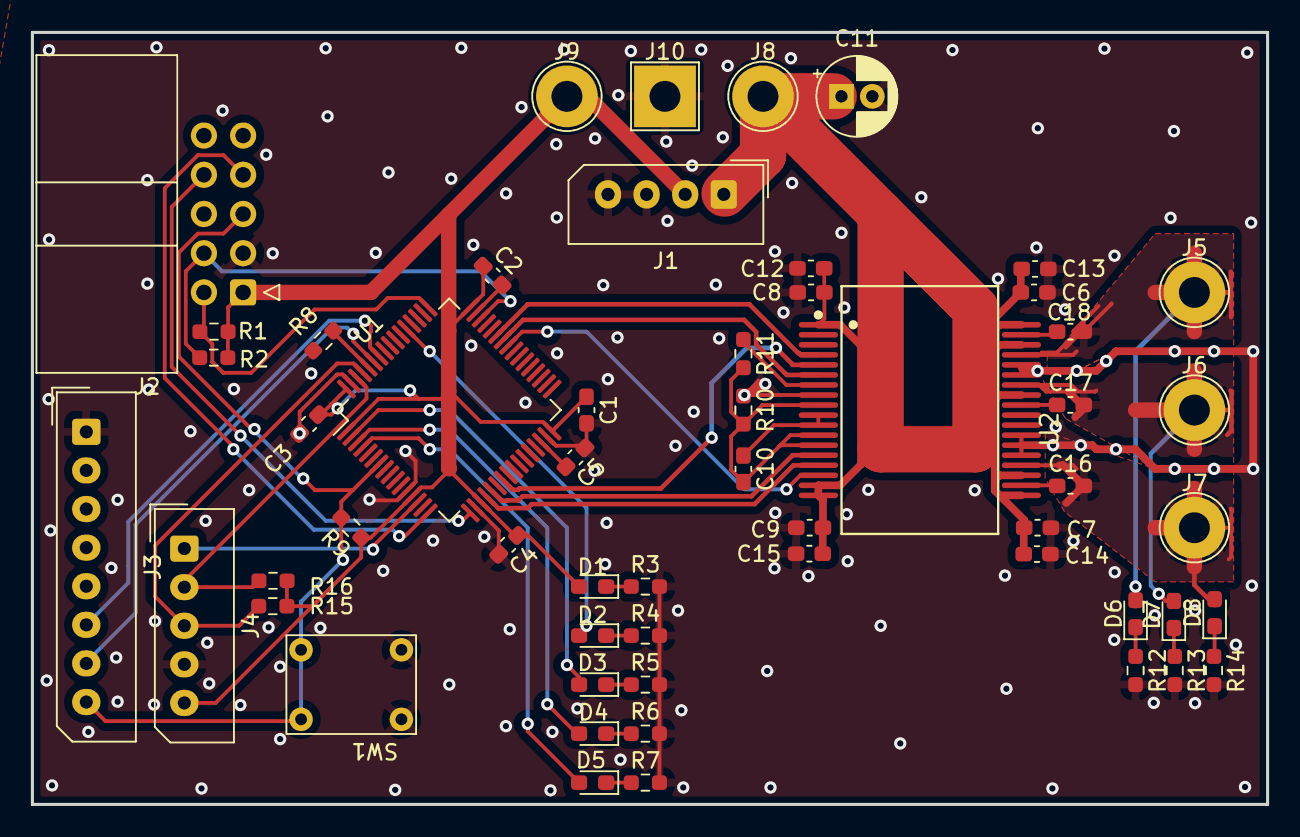
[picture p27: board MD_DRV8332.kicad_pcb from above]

Board: 2 copper layers, 80.0 x 50.0 mm, 55 parts (0 on the bottom side), 42 nets.

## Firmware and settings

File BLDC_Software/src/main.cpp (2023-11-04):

#include <Arduino.h>

void setup() {
  pinMode(PC12, OUTPUT);

	pinMode(PA10,OUTPUT);
	pinMode(PA9,OUTPUT);
	pinMode(PA8,OUTPUT);

	pinMode(PA7,OUTPUT);
	pinMode(PA5,OUTPUT);
	pinMode(PA4,OUTPUT);
	digitalWrite(PA7, HIGH);
	digitalWrite(PA5, HIGH);
	digitalWrite(PA4, HIGH);

	digitalWrite(PC12, HIGH);
	//Serial.begin(115200);
	//Serial.println("Hello World!");
	analogWriteFrequency(20000);
	}


float i = 0;
void loop() {
	int U, V, W = 0;
	U = (sin(i)+1 )* 127;
	V = (sin(i+ 2*PI/3)+1 )* 127;
	W = (sin(i+ 4*PI/3)+1 )* 127;
	// i = i + 0.11; //既製品+乾電池  
	// i = i + 0.003; //自作+Lipo
	//i = i + 0.0025;
	i = i + 0.0078;

	analogWrite(PA10, U);
	analogWrite(PA9, V);
	analogWrite(PA8, W);
}

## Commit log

2023-11-03 画像追加
2023-11-03 モデルの変更
    [core_test.stl, fastener.stl, mount.stl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]
2023-11-03 画像小さくしたよ
2023-11-03 見た目良くした
2023-11-03 詳細追加
2023-11-03 スペルミス修正
2023-11-03 ちょっと追記
2023-11-04 資料追加
